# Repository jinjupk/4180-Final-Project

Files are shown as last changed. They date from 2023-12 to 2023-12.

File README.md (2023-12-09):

# Contactless Car Unlocking System [ECE 4180 Final Project]

Georgia Institute of Technology \
ECE 4180 (Embedded Systems Design)

Pearl Park \
Lawrence Ro \
Swarna Shah 

## Overview

The Contactless Car Unlocking System allows a user to unlock a car with a specific NFC card instead of using a physical key. In the following demonstration, a Buzzcard student ID is scanned at the sensor location to remotely press the unlock button inside of the car using a 5V relay. The system is powered by the car’s battery which is stepped down to a low enough voltage with a voltage regulator. All components are interfaced through a custom printed circuit board (PCB) and housed in a 3D printed enclosure.

 \


## Components
- MBED LPC1768
- uLCD-144-G2 128 by 128 Smart Color LCD
- 5V relay
- PN532 NFC reader
- Custom PCB
- 3D printed housing

## Hardware

A custom 4-layer PCB includes power management, the microcontroller, and peripherals.

- 4-layer PCB
- LTM8053 Switching Regulator (integrated inductor, 6A max output current)
- Dual LP38692 LDO Voltage Regulator (1A output, separate for servo and microcontroller power)
  








## Software



The program runs in three separate threads to manage the NFC scanner and uLCD at the same time. 
- Main Thread - Initializes uLCD and NFC scanner threads.
- uLCD Thread - Displays invalid card and card accepted messages according to card scanned.
- NFC Reader - Asks scanner for ID of card scanned, checks it against a known ID, and turns on relay accordingly.

## Video Demo

<div align="center">
  <a href="https://www.youtube.com/watch?v=it5jC_XB_L4">IMAGE ALT TEXT</a>
</div>

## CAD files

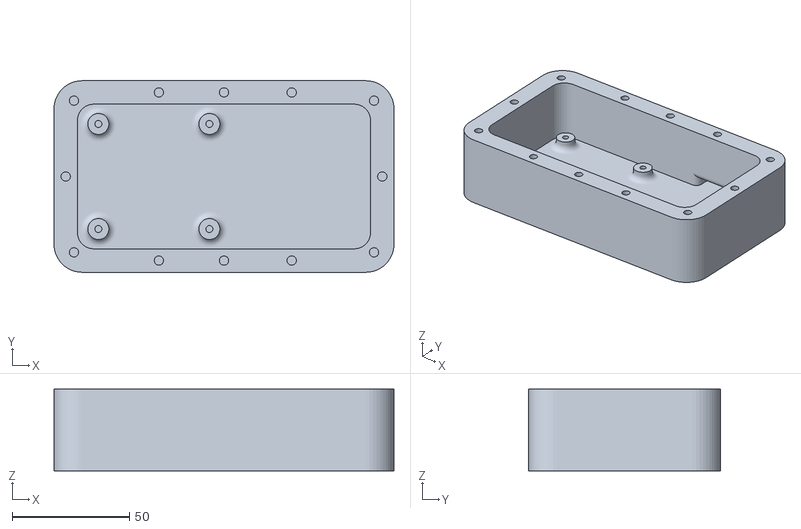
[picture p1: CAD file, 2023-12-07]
hardware/3d_models/Base.obj
145.3 x 81.9 x 35.0

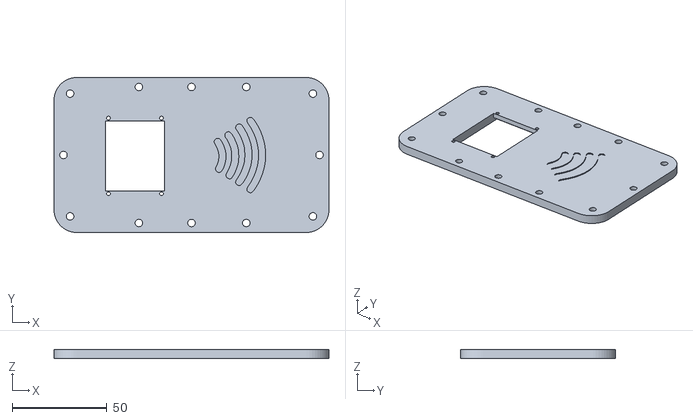
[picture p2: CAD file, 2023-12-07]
hardware/3d_models/Lid.obj
145.3 x 81.9 x 5.00

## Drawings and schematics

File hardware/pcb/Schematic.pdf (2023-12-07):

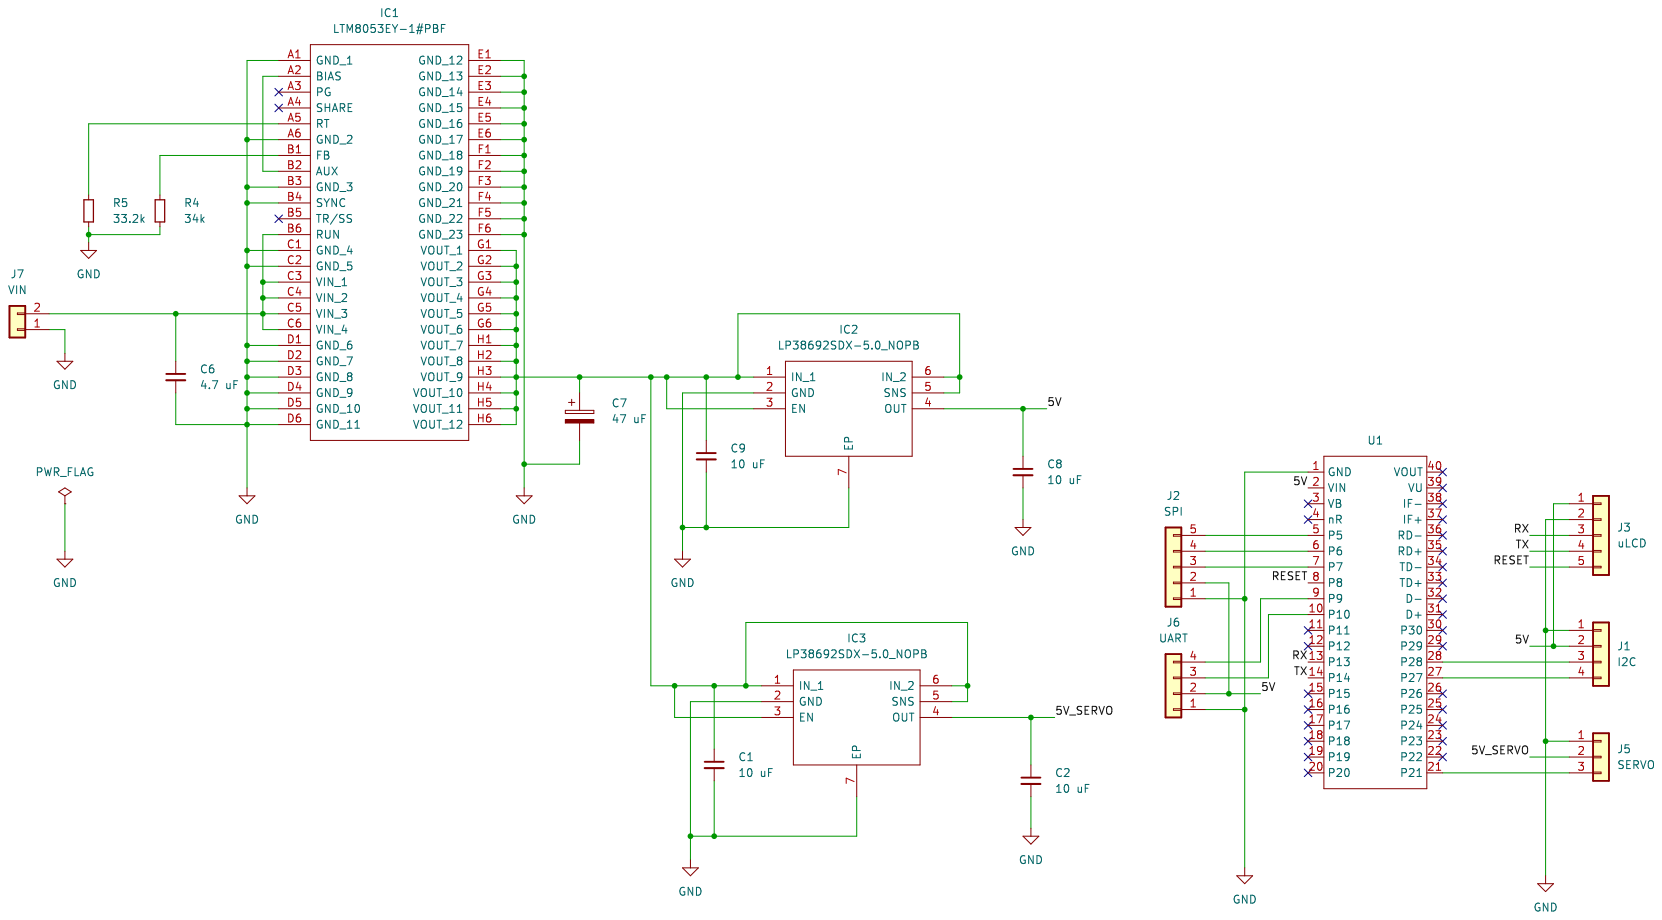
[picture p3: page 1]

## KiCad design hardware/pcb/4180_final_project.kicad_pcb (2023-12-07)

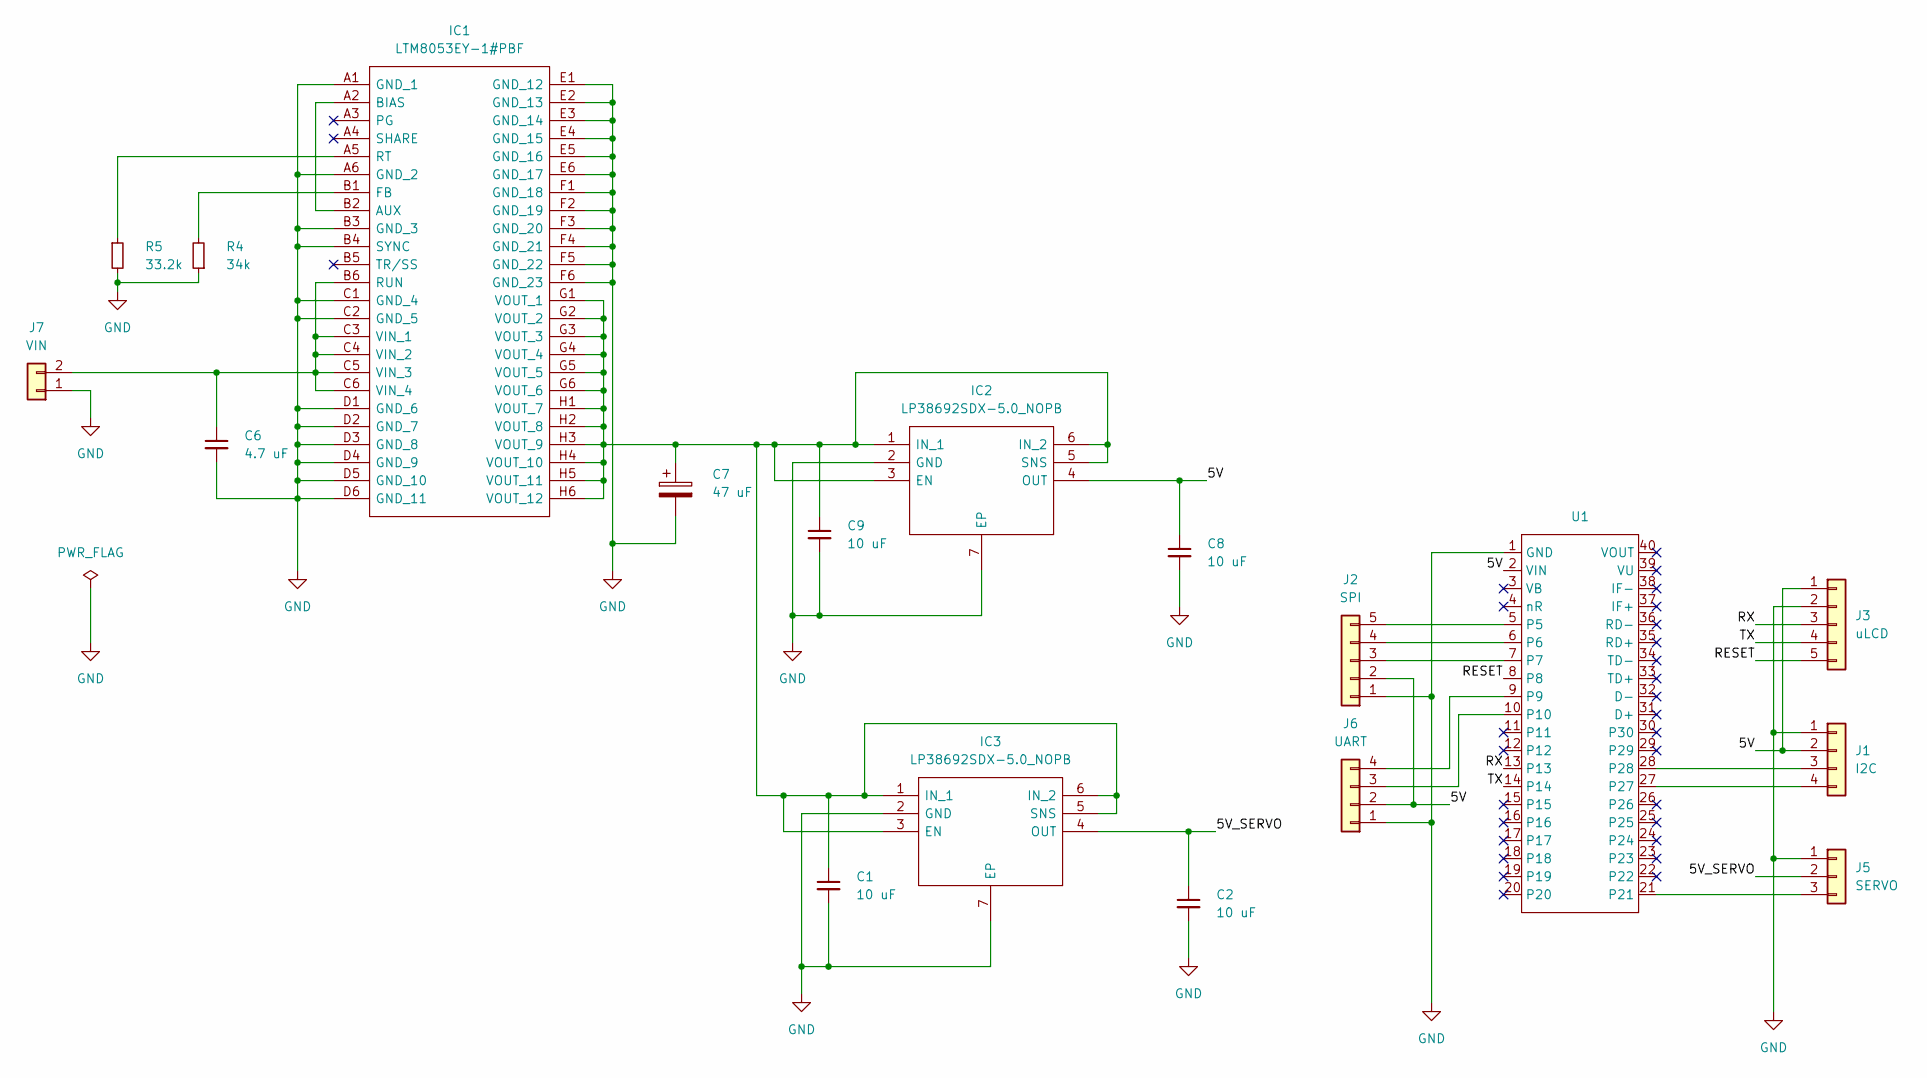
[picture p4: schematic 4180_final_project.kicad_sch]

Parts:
C1, C2, C8, C9: 10 uF; C_0603_1608Metric
C6: 4.7 uF; C_1206_3216Metric
C7: 47 uF; C_1210_3225Metric
IC1: LTM8053EY-1#PBF; BGA48C100P6X8_625X900X352; Mouser Part Number 584-LTM8053EY-1#PBF
IC2, IC3: LP38692SDX-5.0_NOPB; SON95P300X300X80-7N; Mouser Part Number 926-LP38692SDX50NOPB
J1: I2C; PinSocket_1x04_P2.54mm_Vertical
J2: SPI; PinSocket_1x05_P2.54mm_Vertical
J3: uLCD; PinSocket_1x05_P2.54mm_Vertical
J5: SERVO; PinSocket_1x03_P2.54mm_Vertical
J6: UART; PinSocket_1x04_P2.54mm_Vertical
J7: VIN; TerminalBlock_bornier-2_P5.08mm
R4: 34k; R_0603_1608Metric
R5: 33.2k; R_0603_1608Metric
U1: DIP-40_900

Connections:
/5V: C8.1, IC2.4 (OUT), J1.2, J2.2, J3.1, J6.2, U1.2 (VIN)
/5V_SERVO: C2.1, IC3.4 (OUT), J5.2
/RESET: J3.5, U1.8
/RX: J3.3, U1.13
/TX: J3.4, U1.14
GND: C1.2, C2.2, C6.2, C7.2, C8.2, C9.2, IC1.A1 (GND_1), IC1.A6 (GND_2), IC1.B3 (GND_3), IC1.B4 (SYNC), IC1.C1 (GND_4), IC1.C2 (GND_5), IC1.D1 (GND_6), IC1.D2 (GND_7), IC1.D3 (GND_8), IC1.D4 (GND_9), IC1.D5 (GND_10), IC1.D6 (GND_11), IC1.E1 (GND_12), IC1.E2 (GND_13), IC1.E3 (GND_14), IC1.E4 (GND_15), IC1.E5 (GND_16), IC1.E6 (GND_17), IC1.F1 (GND_18), IC1.F2 (GND_19), IC1.F3 (GND_20), IC1.F4 (GND_21), IC1.F5 (GND_22), IC1.F6 (GND_23), IC2.2 (GND), IC2.7 (EP), IC3.2 (GND), IC3.7 (EP), J1.1, J2.1, J3.2, J5.1, J6.1, J7.1, R4.1, R5.2, U1.1 (GND)
unnamed: IC1.A2 (BIAS), IC1.B2 (AUX)
unnamed: IC1.B1 (FB), R4.2
unnamed: IC1.A5 (RT), R5.1
unnamed: C6.1, IC1.B6 (RUN), IC1.C3 (VIN_1), IC1.C4 (VIN_2), IC1.C5 (VIN_3), IC1.C6 (VIN_4), J7.2
unnamed: C1.1, C7.1, C9.1, IC1.G1 (VOUT_1), IC1.G2 (VOUT_2), IC1.G3 (VOUT_3), IC1.G4 (VOUT_4), IC1.G5 (VOUT_5), IC1.G6 (VOUT_6), IC1.H1 (VOUT_7), IC1.H2 (VOUT_8), IC1.H3 (VOUT_9), IC1.H4 (VOUT_10), IC1.H5 (VOUT_11), IC1.H6 (VOUT_12), IC2.1 (IN_1), IC2.3 (EN), IC2.5 (SNS), IC2.6 (IN_2), IC3.1 (IN_1), IC3.3 (EN), IC3.5 (SNS), IC3.6 (IN_2)
unnamed: J1.3, U1.28
unnamed: J1.4, U1.27
unnamed: J2.3, U1.7
unnamed: J2.4, U1.6
unnamed: J2.5, U1.5
unnamed: J5.3, U1.21
unnamed: J6.3, U1.10
unnamed: J6.4, U1.9

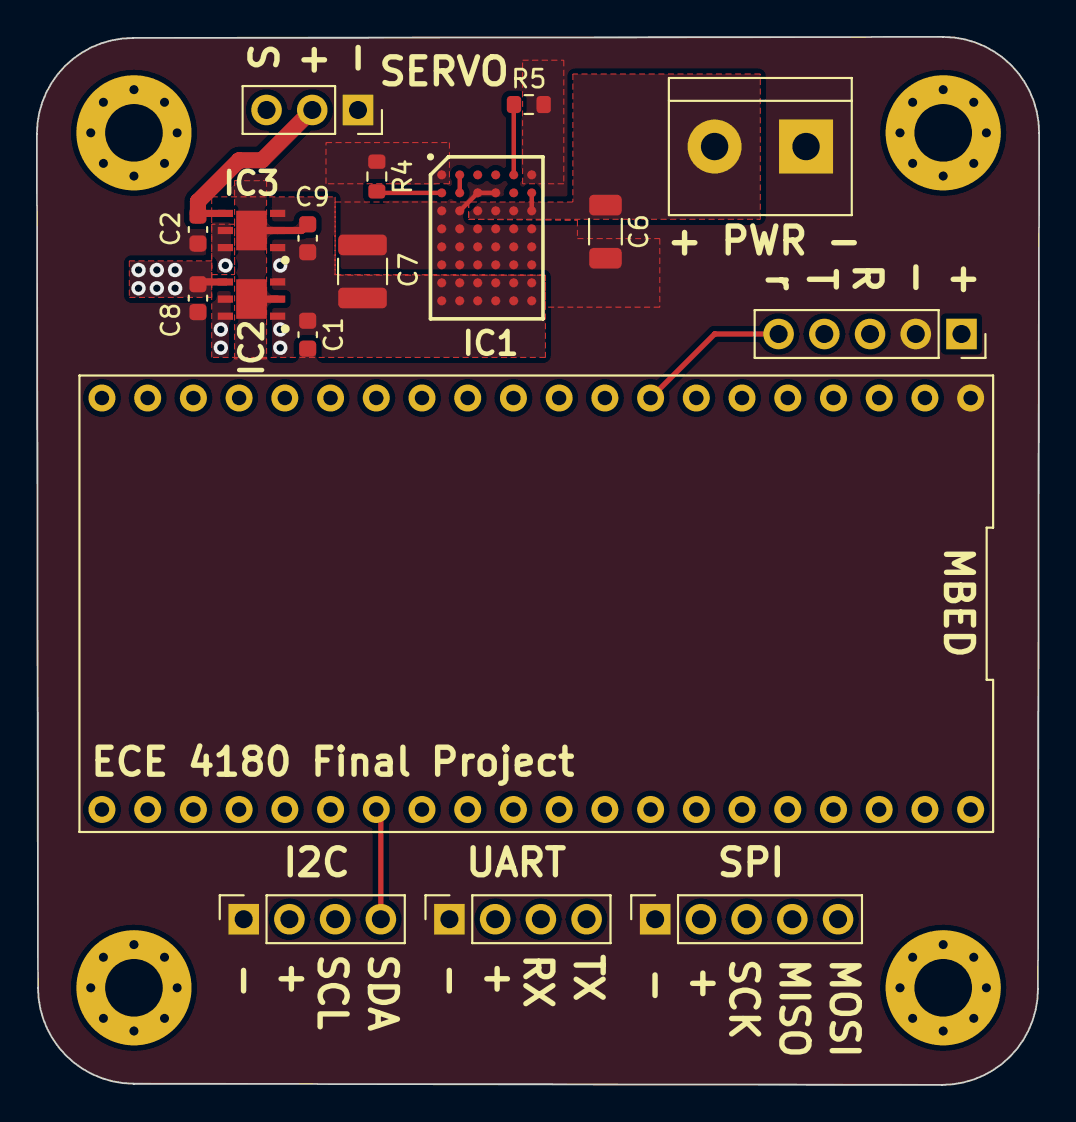
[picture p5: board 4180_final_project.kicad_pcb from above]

Board: 4 copper layers, 55.7 x 58.2 mm, 18 parts (0 on the bottom side), 19 nets.

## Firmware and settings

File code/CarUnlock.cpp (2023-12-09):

#include "mbed.h"
#include "rtos.h"
#include "uLCD_4DGL.h"
#include "Servo.h"
#include "pn532.h"

 
uLCD_4DGL uLCD(p13,p14,p8); // serial tx, serial rx, reset pin;
// I2C i2c(p5, p6, p7);
// DigitalIn pb(p11); 
// Servo servo(p21);
DigitalOut relay(p10);
// Servo servo2(p22);
PN532 NFC(p5, p6, p7, p9);
Serial pc(USBTX,USBRX);
Timer readTimer;
BusOut leds(LED1, LED2, LED3, LED4);
Thread card_read;
Thread uLCD_screen;
#define PEARL 0x4530d12317680
#define SWARNA 0x48033a2c95f80
#define LAWRENCE 0x458569ac95f80

volatile int status = 0;

void invalid_card();
void valid_card();

void unlock() {
    relay = 1;
    Thread::wait(5000);
    relay = 0;
}


void valid_card() {
    uLCD.color(GREEN);
    uLCD.filled_rectangle(15, 40, 125, 120, BLACK);
    uLCD.locate(3, 6);
    uLCD.printf("CARD ACCEPTED");
    status = 0;
    for (int i = 0; i < 3; i++) {
        uLCD.line(50, 88, 61, 96, GREEN);
        uLCD.line(61, 96, 83, 73, GREEN);
        Thread::wait(300);
        uLCD.filled_rectangle(40, 70, 85, 115, BLACK);
        Thread::wait(300);
        if (status == 1) {
           valid_card();
           return;
       } else if (status == 2) {
           invalid_card();
           return;
       }
    }
}
void invalid_card() {
    uLCD.color(RED);
    pc.printf("running invalid card\n");
    uLCD.filled_rectangle(15, 40, 125, 120, BLACK);
    uLCD.locate(3, 6);
    uLCD.printf("INVALID CARD");
    uLCD.locate(3, 8);
    uLCD.printf("ACCESS DENIED");
    status = 0;
    for (int i = 0; i < 3; i++) {
        // pc.printf("for loop run");
        uLCD.line(54, 86, 73, 105, RED);
        uLCD.line(73, 86, 54, 105, RED);
        Thread::wait(300);
        uLCD.filled_rectangle(15, 80, 125, 107, BLACK);
        Thread::wait(300);
        if (status == 1) {
            valid_card();
            return;
        } else if (status == 2) {
            invalid_card();
            return;
        }
    }
}

void uLCD_message() {
    while (1) {
        uLCD.filled_rectangle(15, 40, 125, 120, BLACK);
        uLCD.color(WHITE);
        uLCD.locate(3, 6);
        uLCD.printf("SCAN CARD TO");
        uLCD.locate(4, 8);
        uLCD.printf("UNLOCK CAR");
        while (status == 0);
        pc.printf("new card detected\n\n");
        if (status == 2) {
            invalid_card();
        } else {
            valid_card();
        }
    }
}

// void lock() {
//     pc.printf("locked");
//     servo = 0.0;
// }

void loop() {
    while (1) {
        pc.printf("new loop\r\n");
        uint8_t success, i;
        uint8_t uid[] = { 0, 0, 0, 0, 0, 0, 0 };  // Buffer to store the returned UID
        uint8_t uidLength;                        // Length of the UID (4 or 7 bytes depending on ISO14443A card type)
        static uint8_t lastUID[7];
        static uint8_t lastUIDLength;
        uint8_t newCardFound;
        leds = 0x00;

        // Wait for an ISO14443A type cards (Mifare, etc.).  When one is found
        // 'uid' will be populated with the UID, and uidLength will indicate
        // if the uid is 4 bytes (Mifare Classic) or 7 bytes (Mifare Ultralight)
        success = NFC.readPassiveTargetID(PN532_MIFARE_ISO14443A, uid, &uidLength);
        newCardFound = 0;
        pc.printf("success: %d\r\n", success);
        if (success) {
            if (uidLength == 7) {
                // We probably have a Mifare Classic card ...
                uint64_t cardid = uid[0];
                cardid <<= 8;
                cardid |= uid[1];
                cardid <<= 8;
                cardid |= uid[2];
                cardid <<= 8;
                cardid |= uid[3];
                cardid <<= 8;
                cardid |= uid[4];
                cardid <<= 8;
                cardid |= uid[5];
                cardid <<= 8;
                cardid |= uid[6];
                pc.printf("cardid: %16llX\r\n", cardid);
                if (cardid == PEARL) {
                    pc.printf("Matches Pearl\r\n");
                    status = 1;
                    unlock();
                } else if (cardid == SWARNA) {
                    pc.printf("Matches Swarna\r\n");
                    status = 1;
                    unlock();
                } else if (cardid == LAWRENCE) {
                    pc.printf("Matches Lawrence\r\n");
                    status = 1;
                    unlock();
                } else {
                    pc.printf("Does not match: wrong ID\r\n");
                    status = 2;
                }
            } else {
                pc.printf("uid length is not 7: cannot read card\r\n");
                status = 2;
            }
        }
    }
}

// void pb_hit_callback (void) {
//     pc.printf("button pressed");
// }

int main() {
    pc.printf("starting...");
    // pb.mode(PullUp);
    // // Delay for initial pullup to take effect
    // Thread::wait(1);
    // // Setup Interrupt callback function for a pb hit
    // while (1) {
    //     if (pb.read() == 0) {
    //         pc.printf("button pressed");
    //     }
    // }
    
    // Start sampling pb input using interrupts
    // pb.setSampleFrequency();
    // pc.printf("running main");
    uint32_t versiondata = NFC.getFirmwareVersion();
    if (!versiondata) {
        pc.printf("Didn't find PN53x board\r\n");
        while (1); // halt
    }
    NFC.SAMConfig();
   
    pc.printf("success!\r\n");
    pc.printf("Found chip PN5%lx\r\n", ((versiondata>>24) & 0xFF));
    pc.printf("Firmware ver. %lu.%lu\r\n", (versiondata>>16) & 0xFF,
           (versiondata>>8) & 0xFF);
    relay = 0;
    card_read.start(loop);
    uLCD_screen.start(uLCD_message);
    // uLCD_screen.set_priority(osPriorityLow);
}
